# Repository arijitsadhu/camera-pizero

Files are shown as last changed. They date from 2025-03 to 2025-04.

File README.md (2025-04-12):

# camera-pizero
Raspberry Pi Zero and Raspberry Pi Camera Module based camera

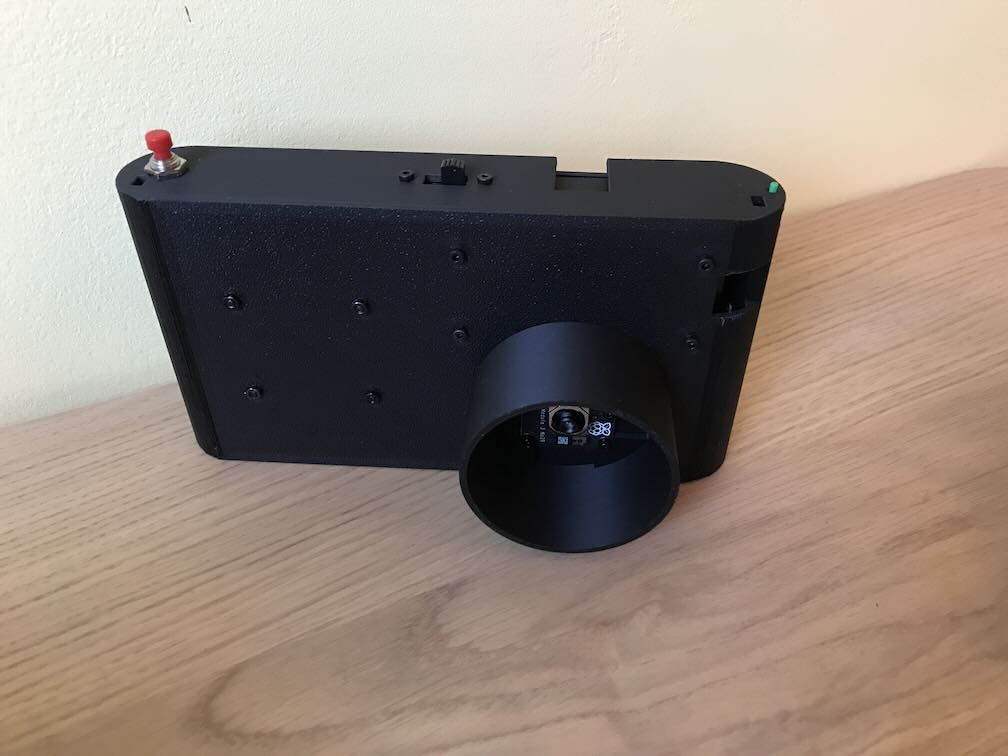
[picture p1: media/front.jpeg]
Camera


I wanted to make an IR camera for landscape photos.

It uses the Raspberry Pi Camera Module 3 NOIR which has autofocus, a Raspberry Pi Zero 2W for the size and ok performance, a generic 3.5in LCD SPI screen from Elecrow I had around, trigger push button hole, on-off switch mount for saving battery power and normal AA instead of one of a kind USB charge-banks and uses printable battery holder to make the project easily reproducible. Note that any Raspberry Pi zero can be used instead or any Raspberry Pi Camera module from 1 to 3.

The camera also has a hole for tripod mount where a nut can be glued if needed, has holes for straps (peak design compatible) and cold shoe accessory mount for viewfinders and other accessories. Do not use a flash as the metal contacts can scratch the print.

TODO: Mount for cokin filters.

## BOM
* Raspberry Pi Zero
* Raspberry Pi Camera Module
* Extendded camera ribbon for pi zero
* 3.5in LCD SPI Raspberry Pi Screen
* 7mm push button
* 2-pin female housing connector
* Mini Slide Switch 2-Position SPDT
* [AA Makeshift Battery Holder 3](https://makerworld.com/en/models/452852-aa-makeshift-battery-holder-1-2-3-4-6-8-10-12#profileId-360121)
* 3xAA Batteries
* Micro-USB cable
* 2x M2.5 4mm screws
* 4x M2.5 6mm screws
* 4x M2 6mm screws
* 4x M2 10mm screws
* 6x M2.5 nuts
* 8x M2 nuts

## Assembly instructions

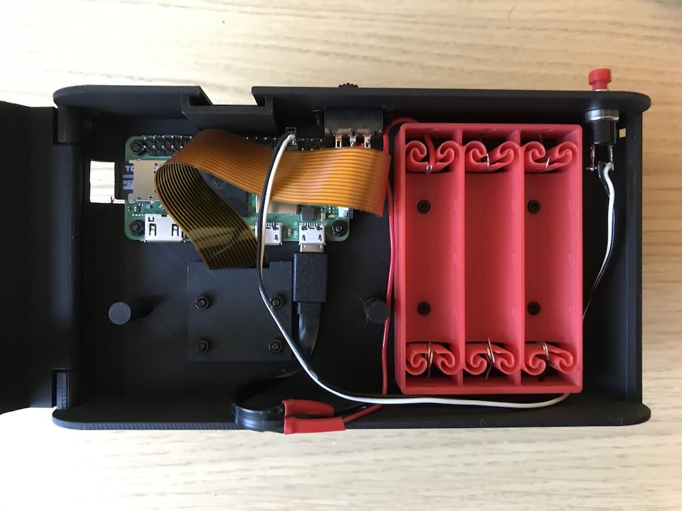
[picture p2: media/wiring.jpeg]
Assembly


1. Wire the push button to the 2-pin female housing connector.
2. Wire the Battery Holder and Slide Switch and the micro usb cable by cutting off the USB-A connector.
3. Connect the camera module to the raspberry pi through the cable hole.
4. Assemble the camera module with the hood on the case with the M2 10mm screws and nuts.
5. Assemble the raspberry pi on the case with the  M2.5 6mm screws and nuts.
6. Assemble the Slide Switch to the case with the M2.5 4mm screws.
7. Assemble the Push Button on the case.
8. Assemble the Battery Holder to the case with 6mm screws and nuts and screw heads on the inside.
9. Connect the push button connector to the pins 33/34 of the raspberry pi.
10. Connect the micro-usb connector to the power connector (right) of the raspberry pi.
11. Connect the screen to the raspberry pi.
12. Assemble the cover to case using a length of spare print filament.
13. Insert memory card if not done prior to assembly.
14. Insert batteries.

Note: During the software installation better use a usb power supply.

## Software
Using the Raspberry Pi OS Lite (64bit) bookworm 2024-11-29 and the code has a hack for an existing bug that will be patched in the future so  will require a code change for future releases.

Prequesistes
* Raspberry Pi OS Lite bookworm

Copy the repository in the Raspberry pi and run the install script:
```
cd camera-pizero/src/
sudo bash install.sh
```

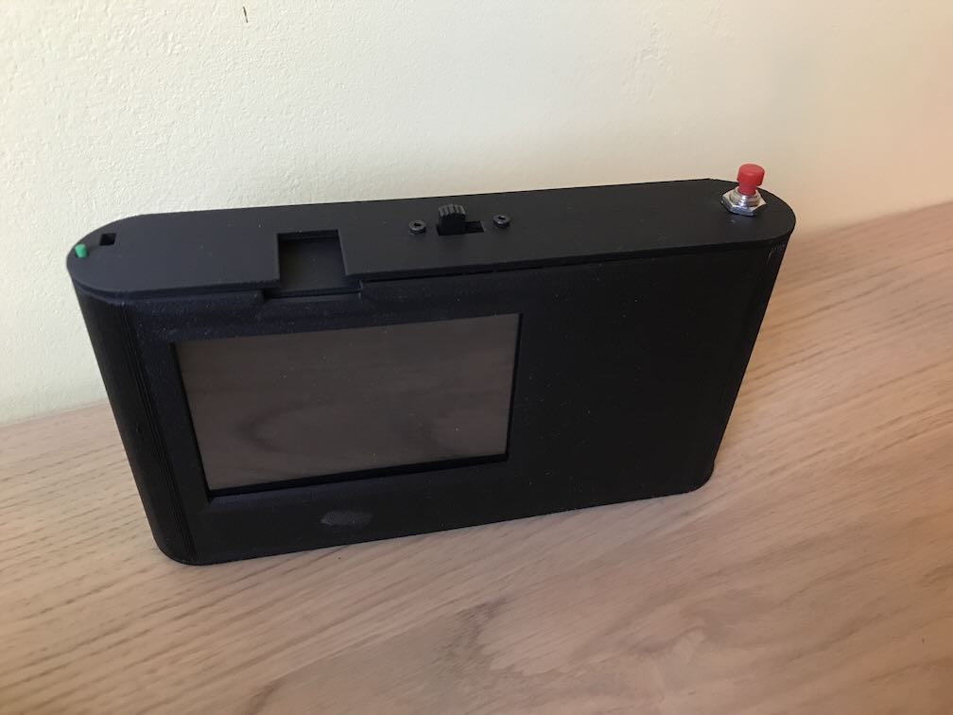
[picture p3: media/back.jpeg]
Assembled


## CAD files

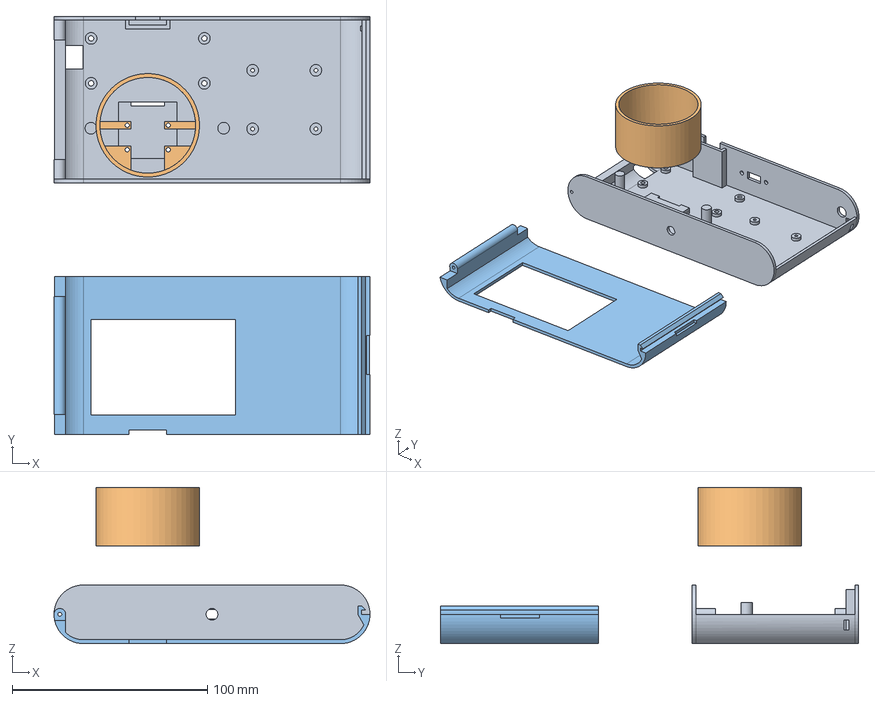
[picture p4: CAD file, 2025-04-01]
case/camera_pizero.FCStd
161.8 x 214.2 x 80.0 mm
Hood001
Cover001

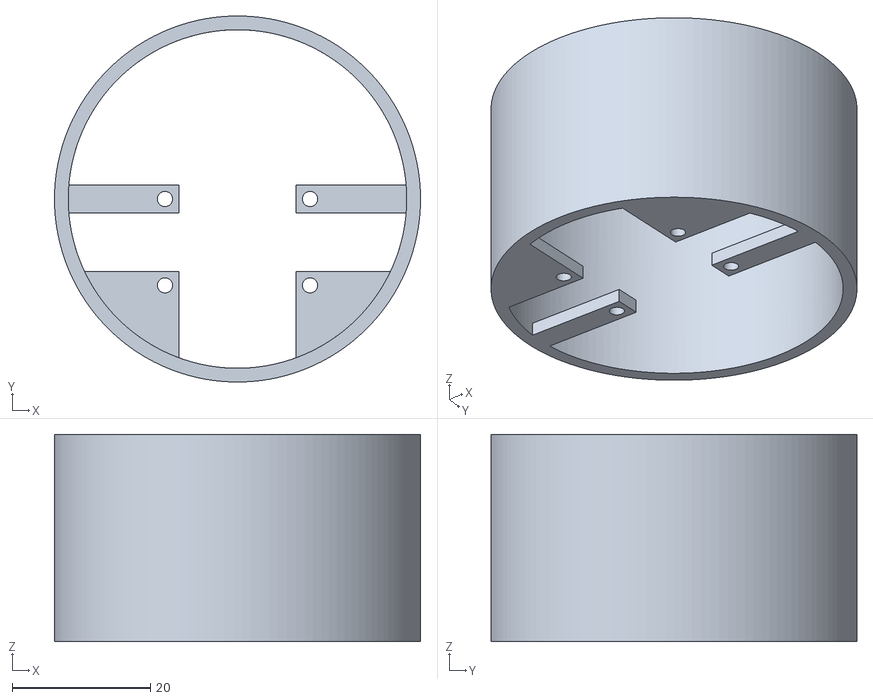
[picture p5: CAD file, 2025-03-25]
case/camera_pizero_hood.stl
53.0 x 53.0 x 30.0

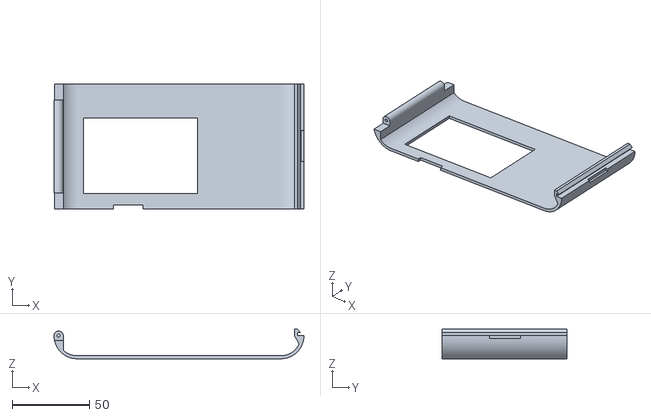
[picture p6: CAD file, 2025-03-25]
case/camera_pizero_cover.stl
161.8 x 80.9 x 19.2

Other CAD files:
case/camera_pizero.3mf
case/camera_pizero.stl

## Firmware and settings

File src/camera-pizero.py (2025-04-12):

#!/usr/bin/python3

from gpiozero import Button
from libcamera import Transform
from picamera2 import Picamera2, Preview, MappedArray
from glob import glob
from os import sync
import cv2

button = Button(13)
frame = 1

def apply_txt(request):
    global frame
    with MappedArray(request, "main") as m:
        cv2.putText(m.array, "%04d" % frame, (0, 30), cv2.FONT_HERSHEY_SIMPLEX, 1, (0, 255, 0), 2)

def main():
    global frame
    picam2 = Picamera2()
    picam2.start_preview(Preview.DRM, width=480, height=320)
    preview_config = picam2.create_preview_configuration({"format": "XRGB8888","size": (480, 320)}, transform=Transform(hflip=1, vflip=1), queue=False)
    capture_config = picam2.create_still_configuration(transform=Transform(hflip=1, vflip=1))
    picam2.configure(preview_config)
    picam2.start()
    try:
        frame = int(sorted(glob("*.jpg"))[-1][:-4]) + 1
    except:
        frame = 1
    print(frame)
    picam2.post_callback = apply_txt
    while True:
        button.wait_for_press()
        picam2.switch_mode_and_capture_file(capture_config, "%04d.jpg" % frame)
        sync()
        print("saved %04d.jpg" % frame)
        frame += 1

if __name__ == "__main__":
    main()

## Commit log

2025-03-25 Initial Design
    [camera_pizero.FCStd]
2025-03-25 Invert pi/camera/screen vertically for sd card left entry
    [camera_pizero.FCStd]
2025-03-25 Leica style complete rounded sides
    [camera_pizero.FCStd]
2025-03-25 Increase wall thickness to 2mm to make it stronger
    [camera_pizero.FCStd]
2025-03-25 Add lens hood
    [camera_pizero.FCStd]
2025-03-25 Angled latch for stronger hold
    [camera_pizero.FCStd]
2025-03-25 Deeper latch for stronger hold, more support for hood and support pillars fro screen
    [camera_pizero.FCStd]
2025-03-25 Cut for cold shoe for deeper accessories
    [camera_pizero.FCStd]
2025-03-25 Wider for power switch and camera ribbon cable
    [camera_pizero.FCStd]
2025-03-25 Update instructions and print files
    [camera_pizero.3mf, camera_pizero.stl, camera_pizero_cover.stl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]
2025-04-01 Fix strap holes and initial code
    [camera_pizero.3mf, camera_pizero.FCStd, camera_pizero.stl]
2025-04-02 Add shot count
    [camera_pizero.3mf]
